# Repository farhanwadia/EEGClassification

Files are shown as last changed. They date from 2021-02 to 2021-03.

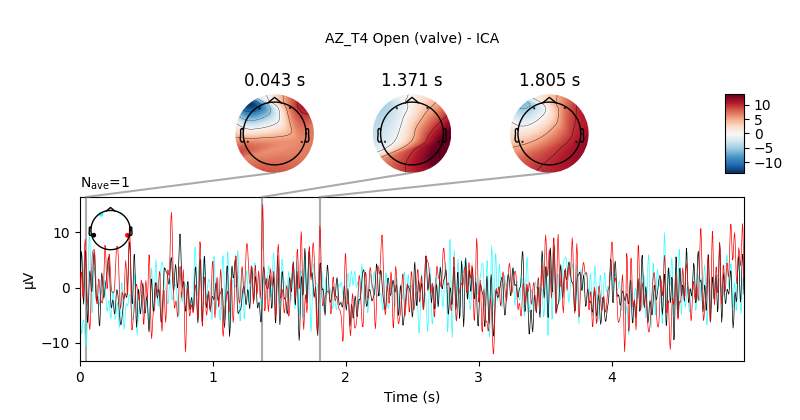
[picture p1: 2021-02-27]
Nov 2020 Filtered Data/5s/Images/ICA Images/AZ_T4 Open (valve) ICA.png

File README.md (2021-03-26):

# Brain Computer Interfaces for Industrial Fluid Flow Control

## Group Members
**Amaani Zuberi**

**Farhan Wadia**

**Jun Sung Park**

**Mrinal Jha** 

**Stephanie DiNunzio**

## Description
This repository consists of all data and software developed for our capstone project.

Programs for collecting EEG data based on covert speech, motor imagery, SSVEP, and eye movements can be found in the `Data Collection Scripts` folder. Follow the instructions in the `Using the Muse Headset for Collecting Raw EEG Signals.pdf` file within that folder to run any of the programs. Note that the MuseLab SDK is not included in this folder and will need to be installed separately.

Raw data files we collected for covert speech model training can be found in the `Nov 2020 Raw Data` and `Feb 2021 Raw Data` folders.

Filtering, time series data outputs, FFT outputs, wavelet transforms, and corresponding graphs were all developed using the `visualization.py` script. Outputs can be found organized in the `Nov 2020 Filtered Data` and `Feb 2021 Filtered Data` folders. 

Model training can be found in the `EEG_Classification_Model_Training.ipynb` notebook. Downloaded model weight files can be found in the `Trained Model Weights` folder. Testing for these models is conducted in the `EEG_Classification_Model_Testing.ipynb` notebook. A breakdown of the results for our final chosen model can be found in the `Final Model Test Results Summary.xlsx` spreadsheet.

Relevant files for implementing the chosen model live in conjunction with a solenoid valve can be found in the `Final Prototype Implementation` folder. Refer to the `Using the Muse Headset for Collecting Raw EEG Signals.pdf` file for further instructions on how to set up the Muse for live EEG streaming, and also refer to `Implementation_README.md`

The `Prototype and Final Design CAD Assemblies` folder contains SOLIDWORKS parts and assemblies showing the mechanical design of our system. The `Electrical Design` folder contains our final and previous versions of the electrical design, and includes the schematic, `.brd` files of the CAD in EAGLE, and `.step` file that can be imported into SOLIDWORKS.

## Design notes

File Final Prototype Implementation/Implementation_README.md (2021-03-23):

# Final Prototype Implementation Files

 - All these files MUST be kept in the same folder
 - If your GPU is not compatible with CUDA, you will need to set use_cuda = False
 - Make sure you change the save file path and subject initials before running
 
For the `output_ bluetooth.py` script, you will need to first pair the Bluetooth module with your computer. The code for Bluetooth pairing is 1234, but if that doesn't work, try 0000. The COM port may be different on your device, so check and change that if needed (may need different syntax for COM port on Mac).

In order to operate the valve, the python script `output_bluetooth.py` must be left continuously running on your computer and paired with the Bluetooth module on the circuit. The computer sends the input to the Bluetooth, not the mobile app. The mobile app will update an online database which the Python code is monitoring for updates to start recording. You will first need to set up the stream with Mind Monitor as you have for all other scripts (see the `Data Collection Scripts` folder for further details).

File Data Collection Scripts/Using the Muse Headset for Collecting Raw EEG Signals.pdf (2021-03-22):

# Using Muse 2016

# For recording/streaming EEG Raw Data

# Required Devices / Software

## - Phone or Tablet

- Need to install Mind Monitor App

## - Computer

- Need to install MuseLab (files in google drive folder) (https://drive.google.com/drive/folders/1IQV2IxdR8nq0KHTpxT8a-IwdV5VQzaGj?usp=sharing)
- Need to have python installed

## NOTE: My instructions are for using Windows 10, unsure if there are differences using MacOS

## Also note: The Mind Monitor App and MuseLab both have recording functions to export to CSV, however control of duration and ability to do file naming based on classification is limited and more time consuming than using python script

# 1. Connect Muse to phone/tablet

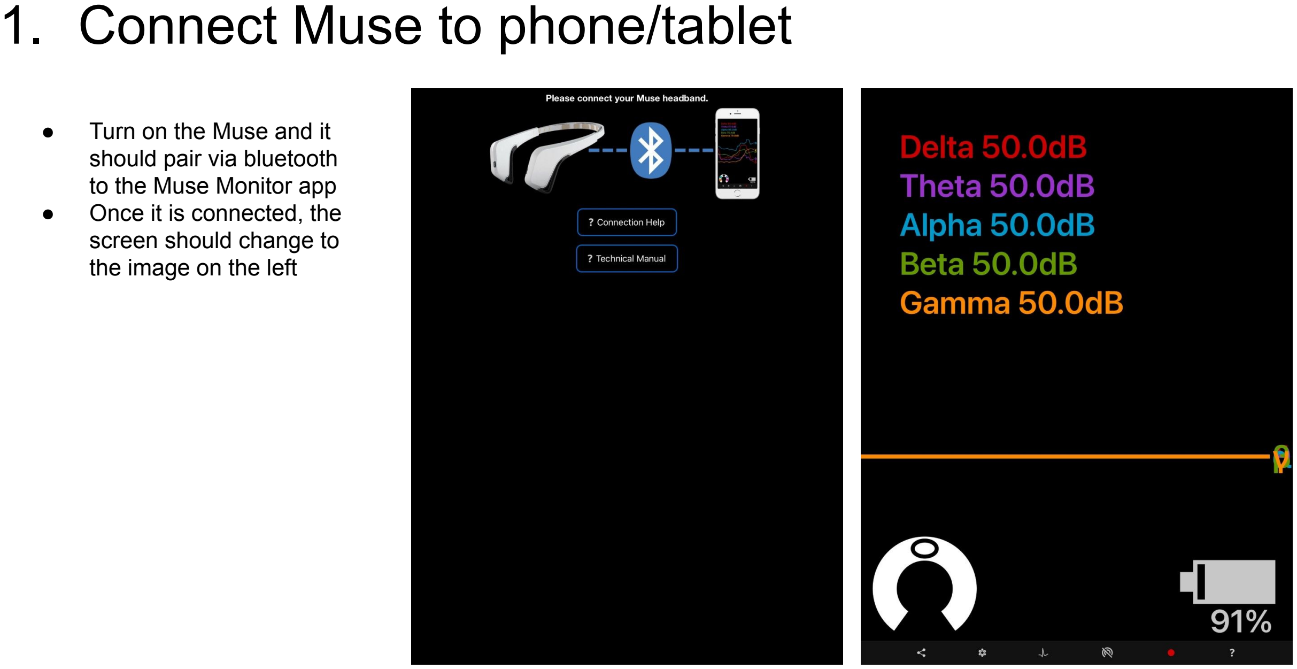
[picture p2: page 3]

- Turn on the Muse and it
should pair via bluetooth
to the Muse Monitor app
- Once it is connected, the screen should change to
the image on the left

# 2. Using the Muse Monitor App

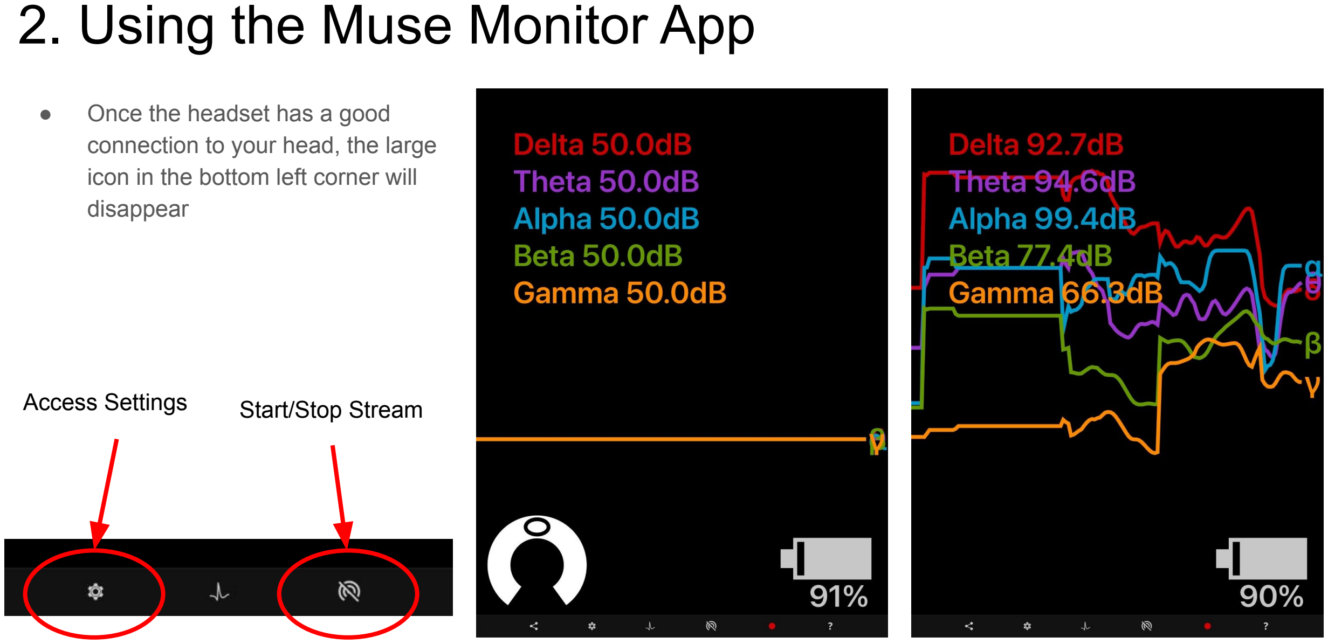
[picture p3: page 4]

- Once the headset has a good connection to your head, the large icon in the bottom left corner will disappear

Access Settings Start/Stop Stream

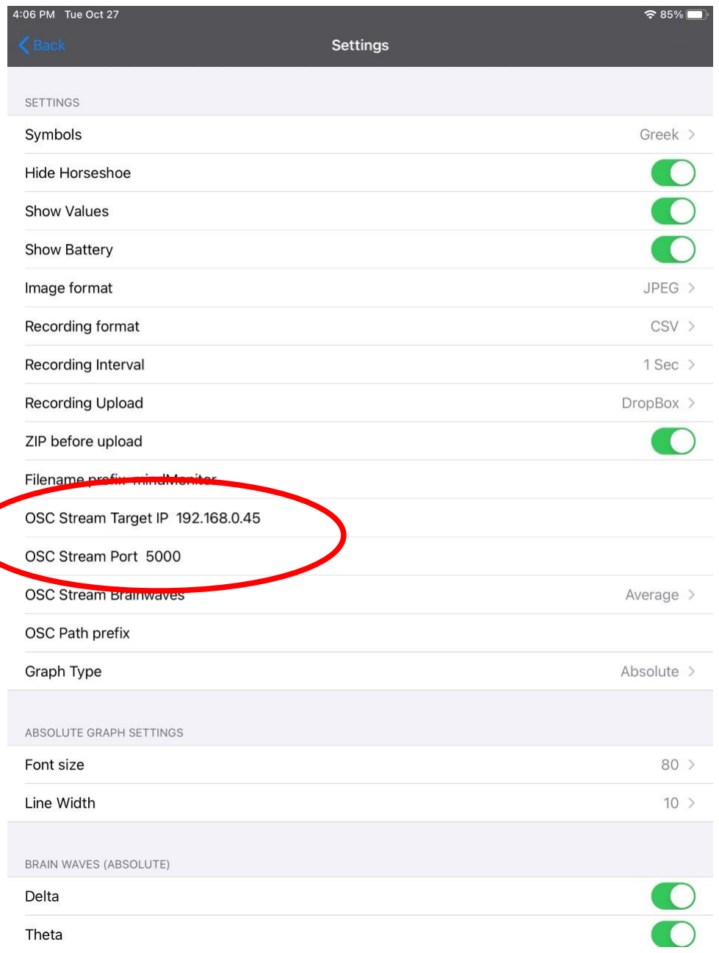
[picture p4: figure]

# 2. Using the Muse Monitor App Cont

- In order to stream to your computer, both devices must be connected to the same network
- If your computer has an ethernet connection, consider using your computer to create a hotspot for your phone or tablet, or switch to wifi
- OSC Stream Target IP must match the IP address of your computer
- Type ipconfig into the command prompt to check your IP address
- OSC Stream port must match the port used in MuseLab (we will use 5000)

# 3. Using MuseLab

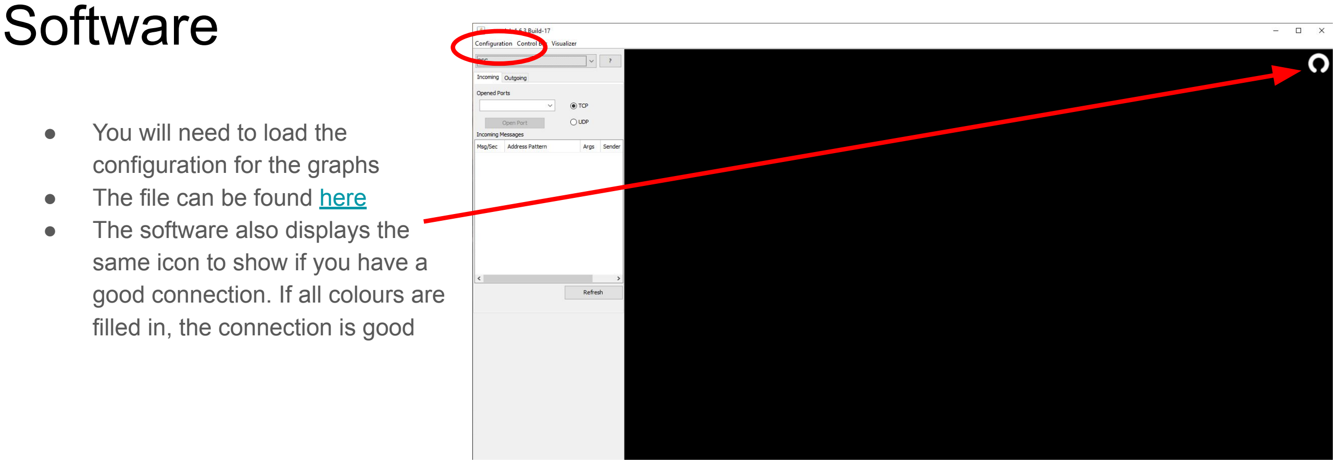
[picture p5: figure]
Software; ● You will need to load the configuration for the graphs; The file can be found; here; ● The software also displays the same icon to show if you have a good connection. If all colours are filled in, the connection is good

# 3. Using MuseLab

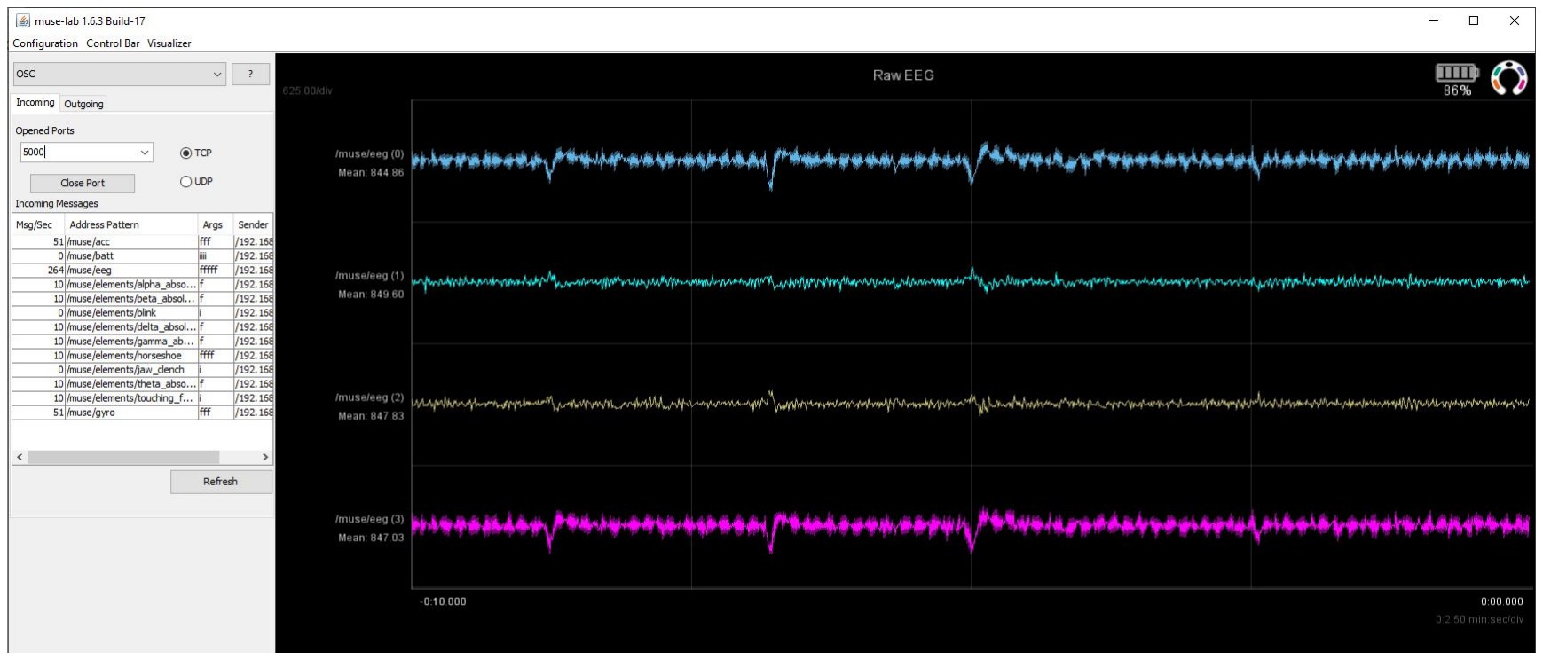
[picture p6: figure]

# Software Cont

- Open TCP Port 5000
- If the data is streaming correctly, it should look something like this
- If it is not streaming, try checking your settings on the Mind Monitor app and stopping and starting the stream on the app again
- Note: Keep in mind that if your computer is not using a static IP, it can change between uses. So you may want to double check this first, if it is not streaming.

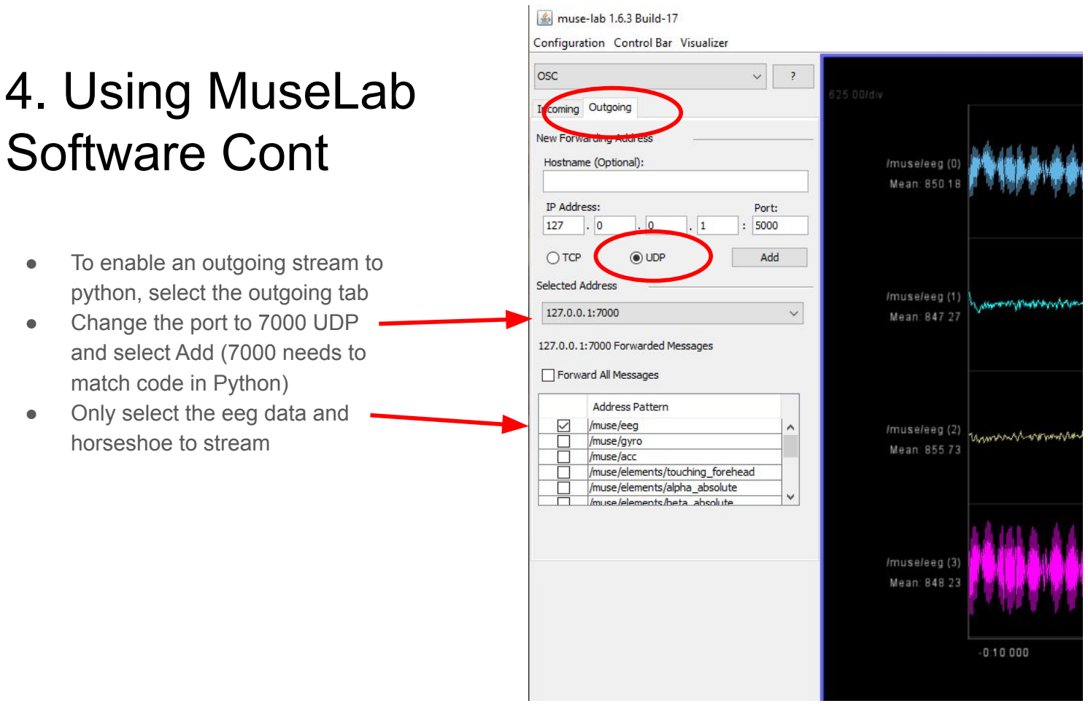
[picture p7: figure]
4. Using MuseLab Software Cont; ● To enable an outgoing stream to python, select the outgoing tab ● Change the port to 7000 UDP and select Add (7000 needs to match code in Python) ● Only select the eeg data and horseshoe to stream

# 5. Using Muse with Python

## - Run code for associated method

## a) SSVEP

# 5. a) - SSVEP Data Collection - Step 1

Open the SSVEP Data Collection.py file and scroll to the main() function at the bottom.

Change the subject to your initials and folderPath to a valid folder path where you will save all your files

Complete trials 1 to 48. Modify startTrialNum and endTrialNum if you do not want to do all these trials at once and only want to do selected trials in between, or leave it as shown to do all the trials at once

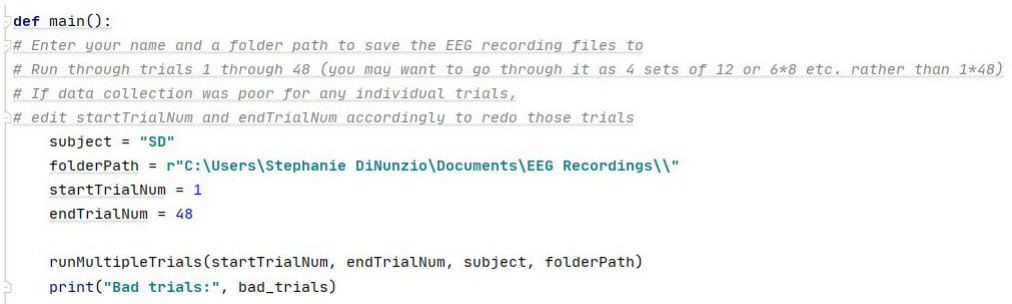
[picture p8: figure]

Run the program

# 5. a) - SSVEP Data Collection - Step 2

At the start of each trial, a rest screen will show for 10 -15s . EEG data will be recorded as you rest. The rest screen also informs you which side of the screen you will be looking at in the next step.

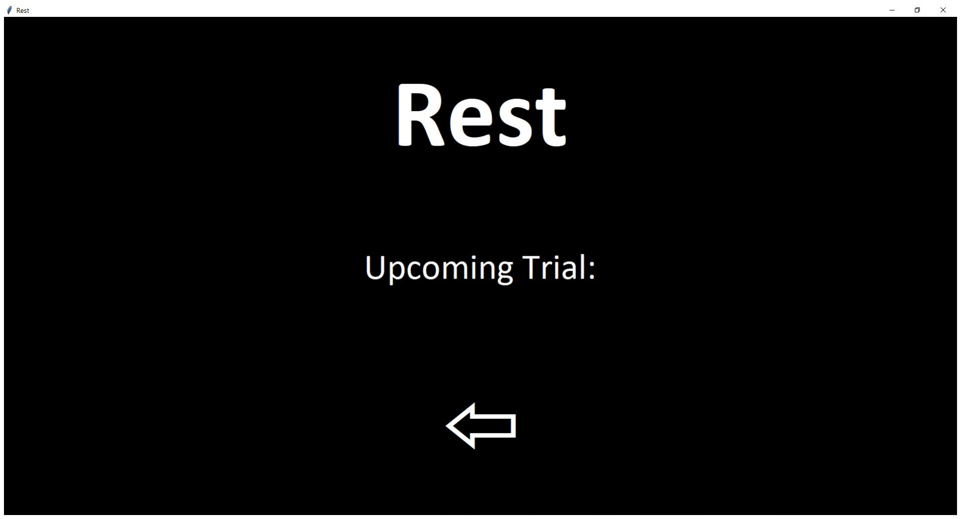
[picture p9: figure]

# 5. a) - SSVEP Data Collection - Step 3

Stare at the flashing checkerboard and red dot on the side of the screen indicated to you. EEG data will be recorded as you do this

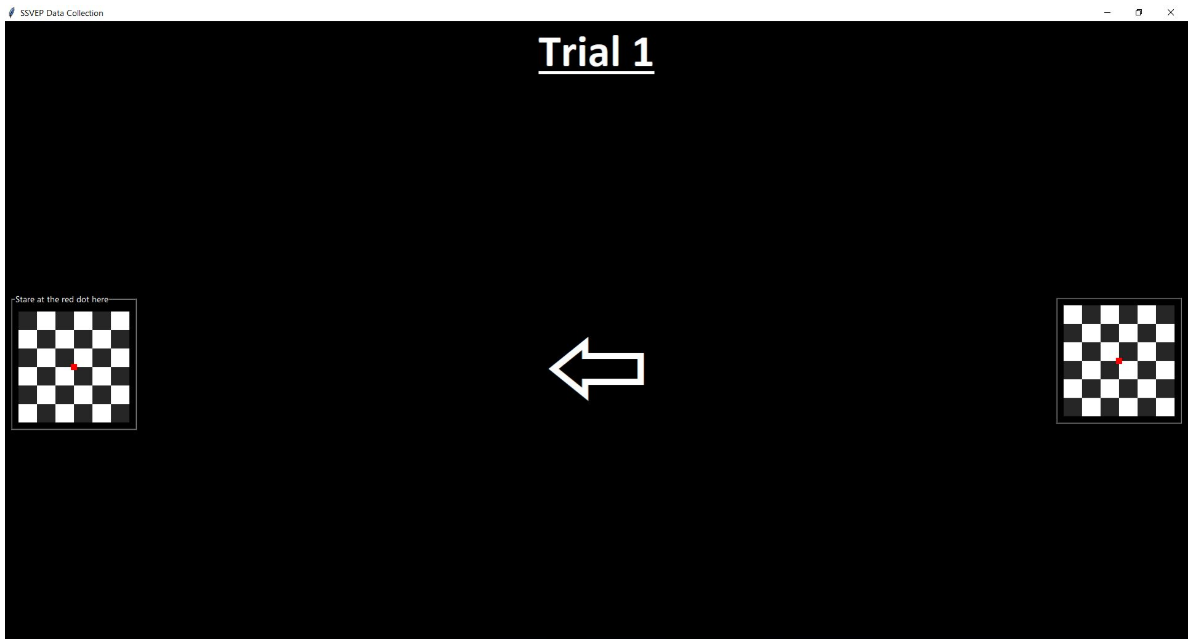
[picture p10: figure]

# 5. a) - SSVEP Data Collection - Step 4

After steps 2 and 3 have been completed for all the trials chosen in step 1, check the Python console to see if any recordings had a poor connection.

If there is a message similar to the one shown below, go back to step 1 and repeat those particular trials

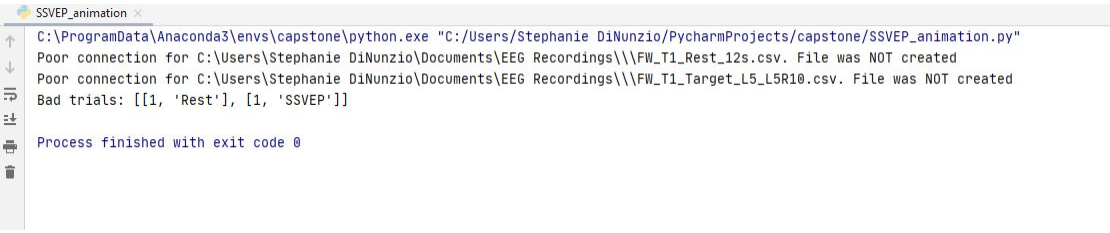
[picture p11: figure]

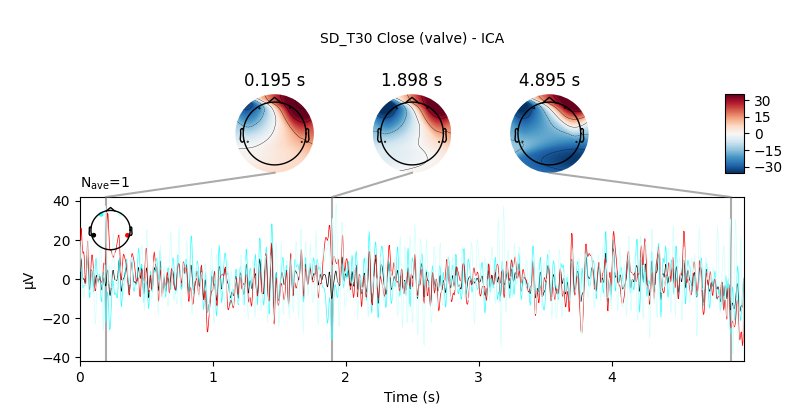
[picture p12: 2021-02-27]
Nov 2020 Filtered Data/5s/Images/ICA Images/SD_T30 Close (valve) ICA.png

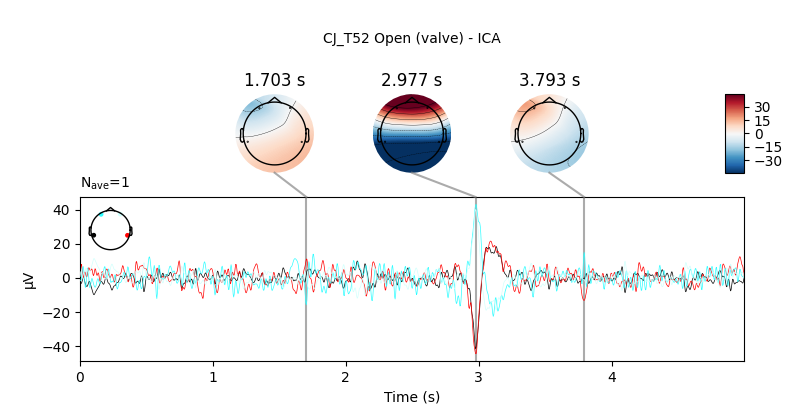
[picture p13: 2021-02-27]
Nov 2020 Filtered Data/5s/Images/ICA Images/CJ_T52 Open (valve) ICA.png

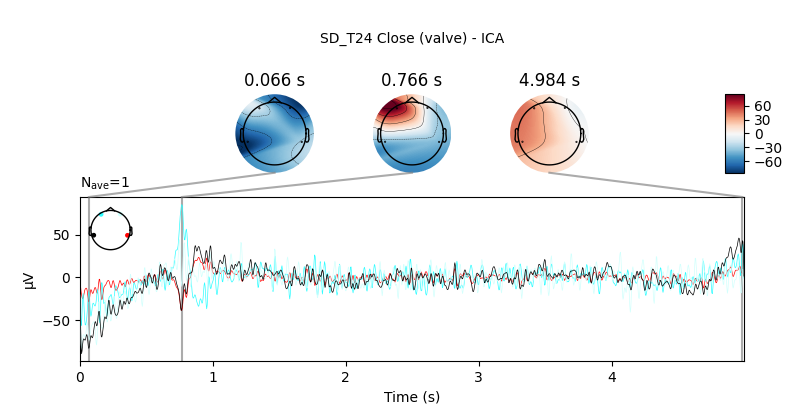
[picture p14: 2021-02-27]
Nov 2020 Filtered Data/5s/Images/ICA Images/SD_T24 Close (valve) ICA.png

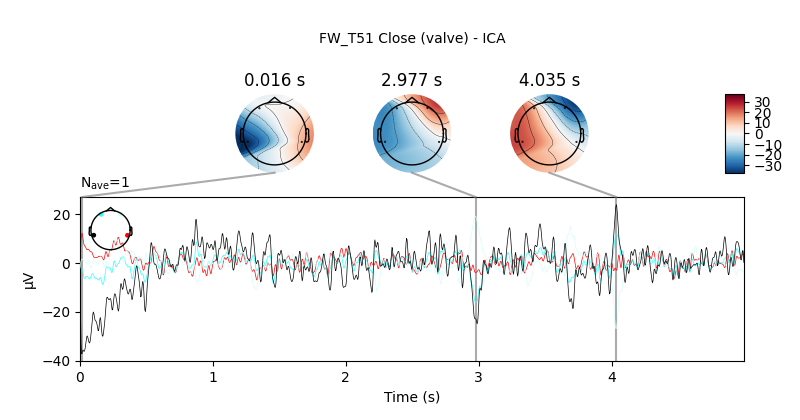
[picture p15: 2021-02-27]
Nov 2020 Filtered Data/5s/Images/ICA Images/FW_T51 Close (valve) ICA.png

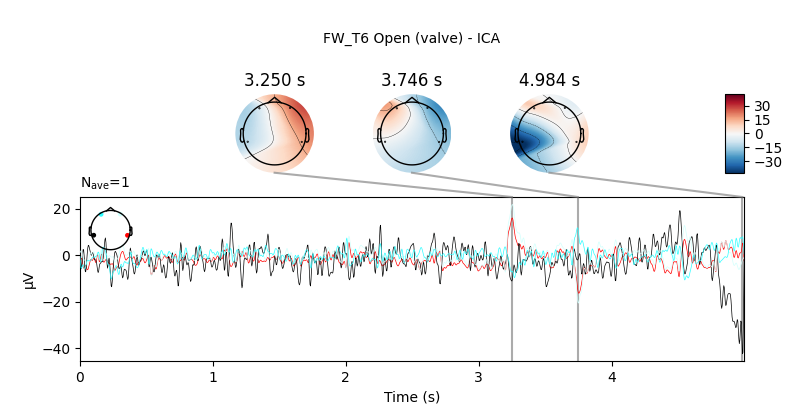
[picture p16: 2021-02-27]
Nov 2020 Filtered Data/5s/Images/ICA Images/FW_T6 Open (valve) ICA.png

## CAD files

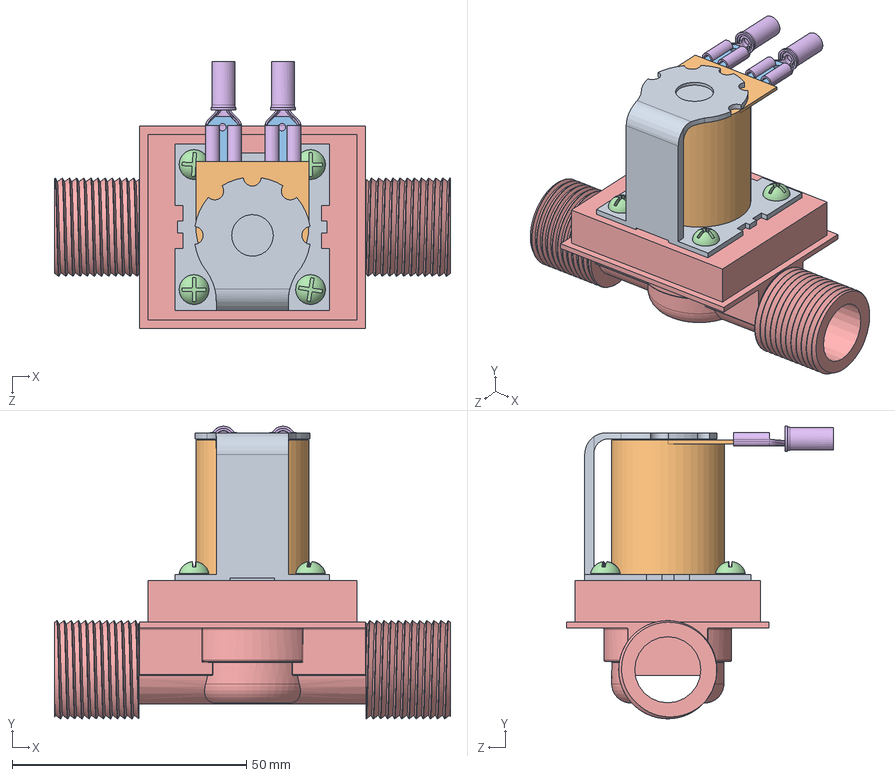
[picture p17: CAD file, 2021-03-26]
Prototype and Final Design CAD Assemblies/Other Assemblies/assemb2.SLDASM
84.6 x 62.5 x 56.9 mm
CAGE
LEAD x 2
screw x 4
Solenoid

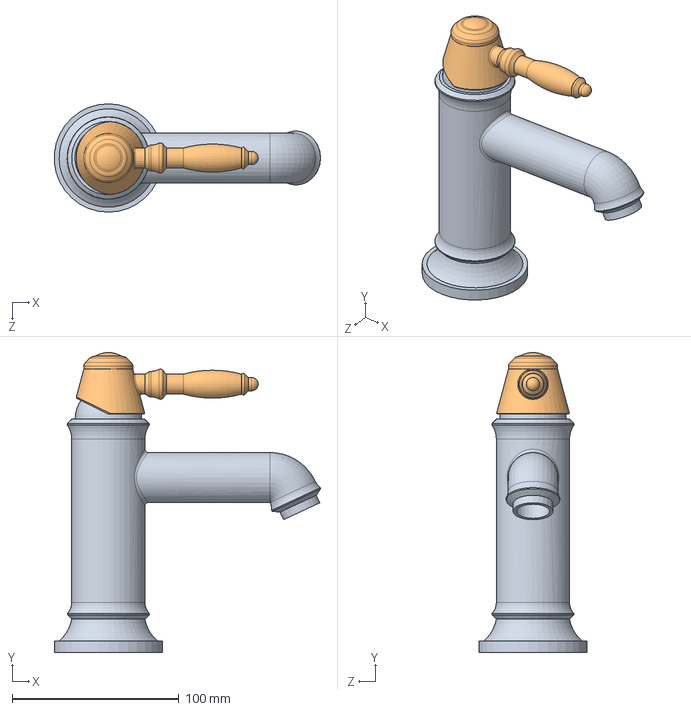
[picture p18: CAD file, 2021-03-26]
Prototype and Final Design CAD Assemblies/Parts/Bathroom faucet/Bathroom_faucet.SLDASM
159.7 x 180.0 x 65.0 mm
base
Handle

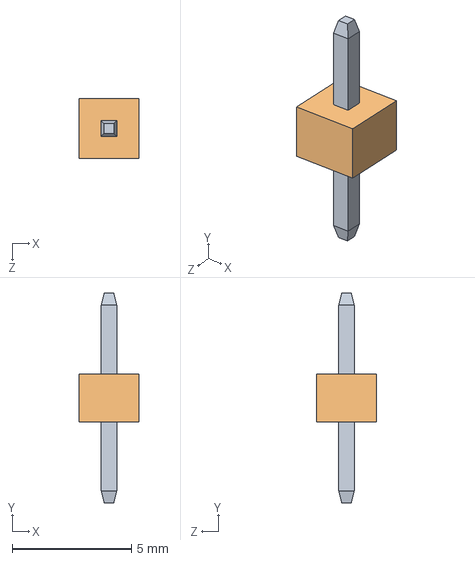
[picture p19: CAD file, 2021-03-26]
Prototype and Final Design CAD Assemblies/Parts/Jumper.SLDASM
2.50 x 8.80 x 2.50 mm
Pin
Socket

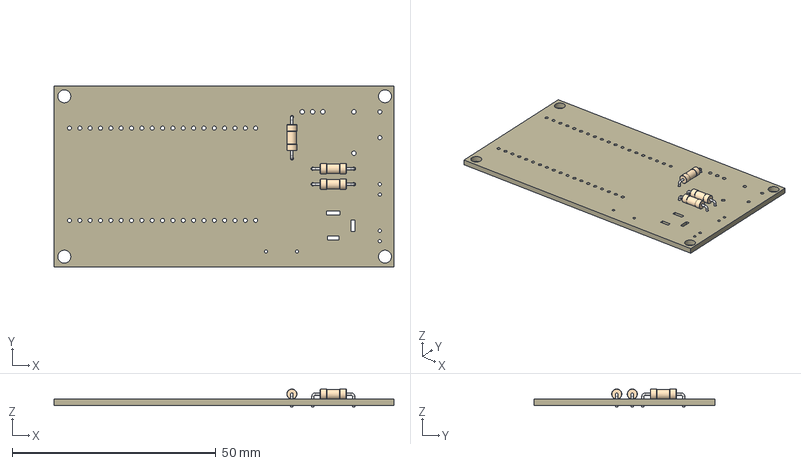
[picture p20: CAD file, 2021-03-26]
Electrical Design/capstone electrical circuit v11.step
83.5 x 44.4 x 4.42 mm
Board
DO41-10
0207/10 x 3
2,54/1,0 x 2
ESP32-DEVKITC
DCJ0202

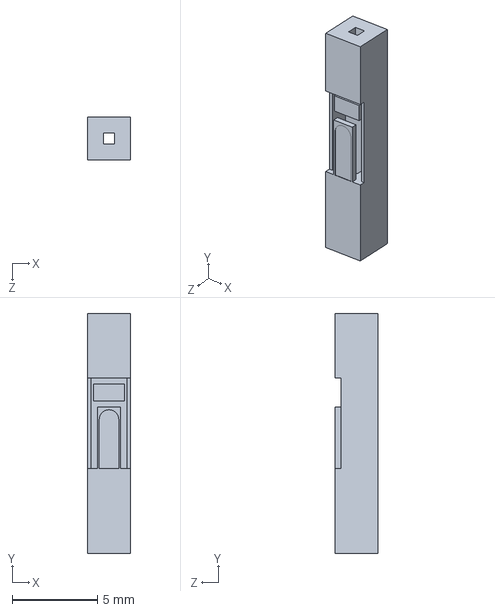
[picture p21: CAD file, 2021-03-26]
Prototype and Final Design CAD Assemblies/Parts/Socket.SLDPRT
2.50 x 14.1 x 2.50 mm

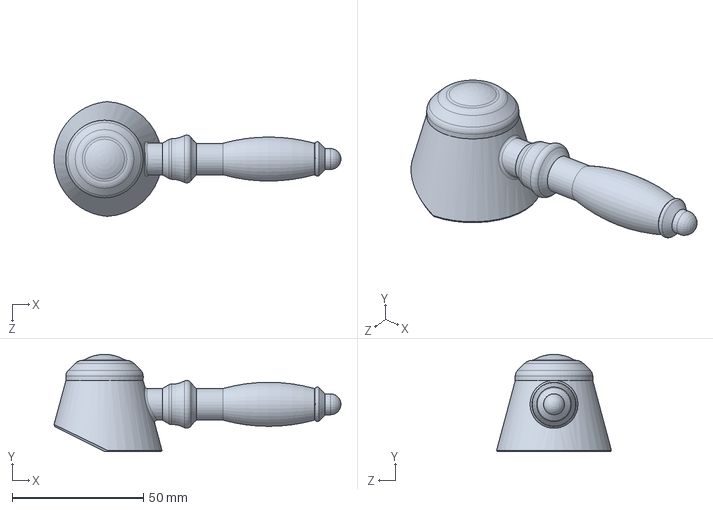
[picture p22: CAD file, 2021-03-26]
Prototype and Final Design CAD Assemblies/Parts/Bathroom faucet/Handle.SLDPRT
109.2 x 37.0 x 43.7 mm

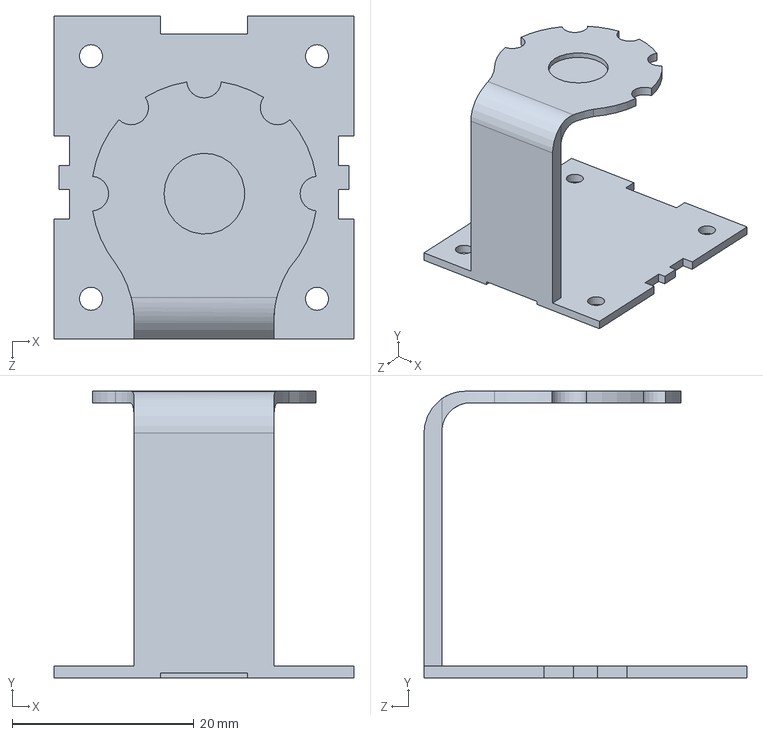
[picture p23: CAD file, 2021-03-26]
Prototype and Final Design CAD Assemblies/Parts/CAGE.SLDPRT
33.0 x 31.5 x 35.6 mm

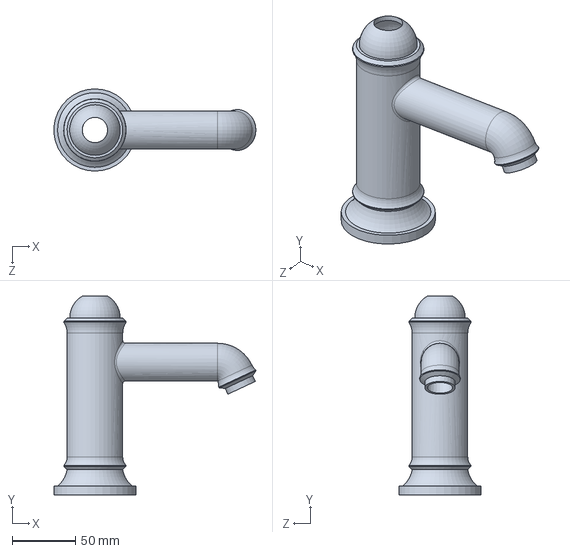
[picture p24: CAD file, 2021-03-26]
Prototype and Final Design CAD Assemblies/Parts/Bathroom faucet/base.SLDPRT
159.7 x 157.3 x 65.0 mm

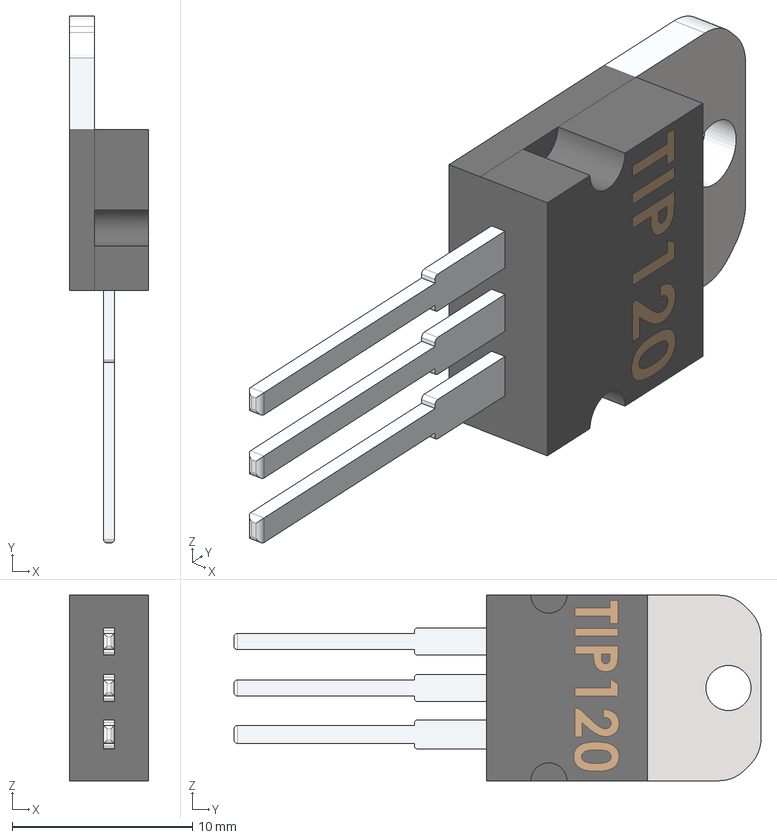
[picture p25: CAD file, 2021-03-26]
Prototype and Final Design CAD Assemblies/Parts/TIP120.step
4.39 x 29.2 x 10.3 mm

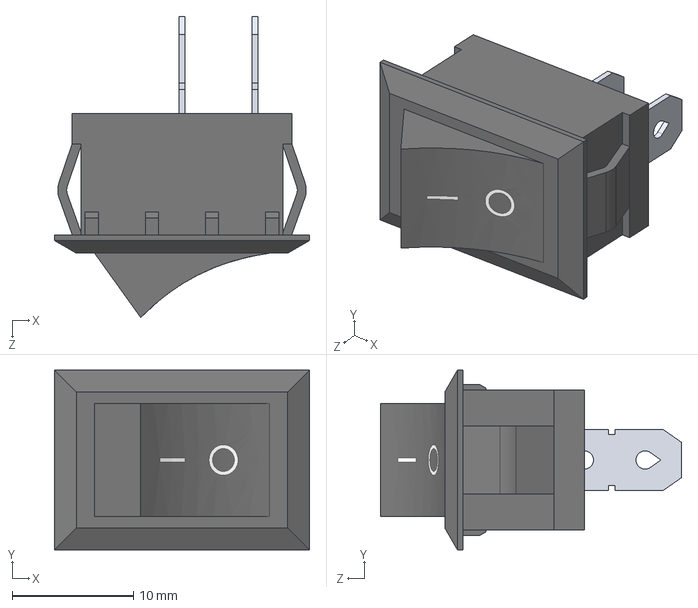
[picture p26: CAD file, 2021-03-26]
Prototype and Final Design CAD Assemblies/Parts/RockerSwitch.STEP
21.0 x 14.8 x 24.8 mm

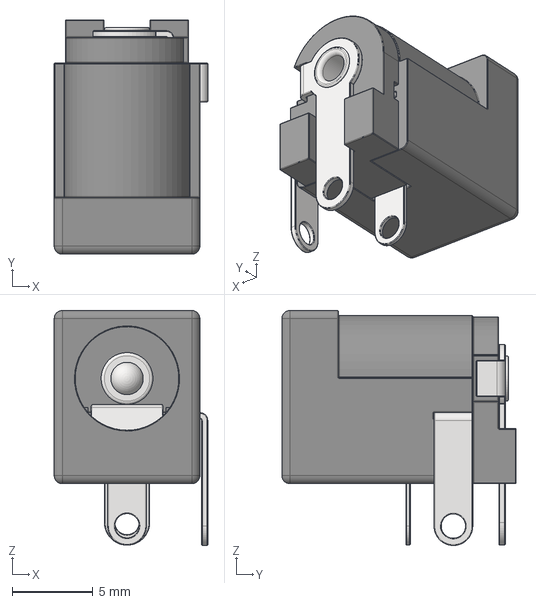
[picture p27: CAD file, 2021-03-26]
Prototype and Final Design CAD Assemblies/Parts/Power Barrel Connector Jack 694106301002.stp
9.49 x 14.5 x 14.5 mm

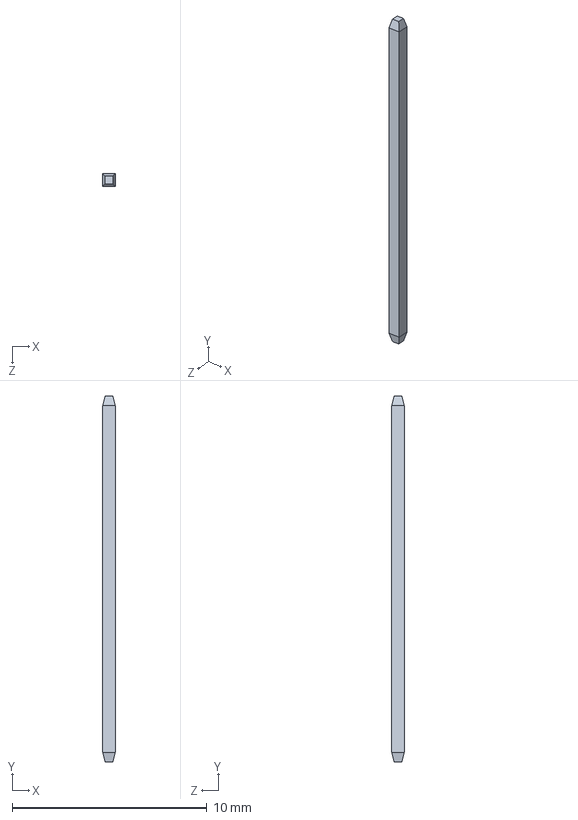
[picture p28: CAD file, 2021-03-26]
Prototype and Final Design CAD Assemblies/Parts/Pin.SLDPRT
0.65 x 18.8 x 0.65 mm

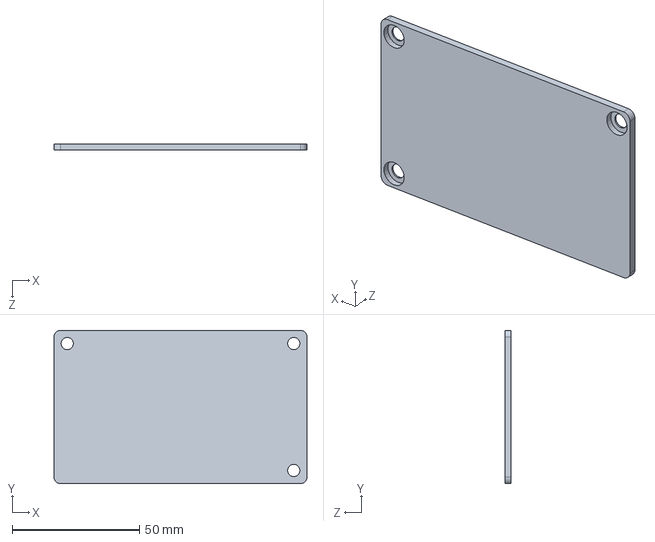
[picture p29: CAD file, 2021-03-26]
Prototype and Final Design CAD Assemblies/Parts/caselid.SLDPRT
99.3 x 60.2 x 2.54 mm

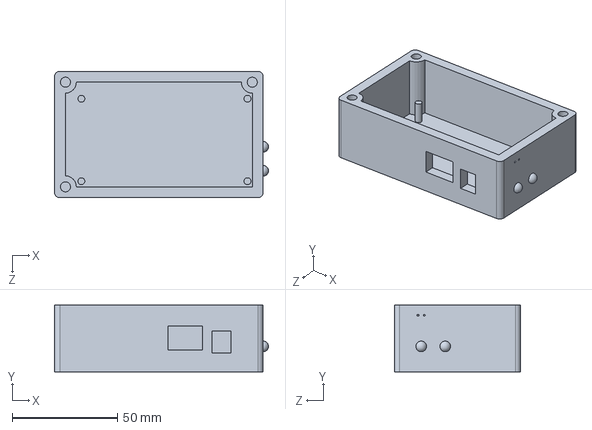
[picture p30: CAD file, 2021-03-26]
Prototype and Final Design CAD Assemblies/Parts/case4.SLDPRT
101.8 x 31.8 x 60.2 mm

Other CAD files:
Prototype and Final Design CAD Assemblies/Parts/Power Diode 1N4001.step
Prototype and Final Design CAD Assemblies/Parts/Solenoid.SLDPRT
Prototype and Final Design CAD Assemblies/Parts/cylinder.SLDPRT
Prototype and Final Design CAD Assemblies/Parts/LEAD.SLDPRT
Electrical Design/Previous Versions/v1/capstone electrical circuit v1.step
Electrical Design/Previous Versions/v2/capstone electrical circuit v4.step
Prototype and Final Design CAD Assemblies/Parts/55675-1.SLDPRT
Prototype and Final Design CAD Assemblies/Parts/LED 3mm, Green, Thru-hole, Right Angle PCB 2.stp
Prototype and Final Design CAD Assemblies/Parts/LED 3mm, Red, Thru-hole, Right Angle PCB 2.stp
Prototype and Final Design CAD Assemblies/Parts/RockerSwitch.x_t
Prototype and Final Design CAD Assemblies/Parts/screw.SLDPRT

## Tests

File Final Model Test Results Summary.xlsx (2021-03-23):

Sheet: Testing Notebook Output
Set | Notebook Output
Training | Prediction: 1 | Label: 1 | Status: Prediction Correct | File: /content/EEGClassification//Feb 2021 Filtered Data//5s//OPEN//SD_T5 Open (valve)_(1) - Filtered
Training | Prediction: 0 | Label: 1 | Status: Prediction Incorrect | File: /content/EEGClassification//Nov 2020 Filtered Data//5s//OPEN//AZ_T39 Open (valve) - Filtered
Training | Prediction: 1 | Label: 1 | Status: Prediction Correct | File: /content/EEGClassification//Feb 2021 Filtered Data//5s//OPEN//CJ_T35 Open (valve)_(2) - Filtered
Training | Prediction: 1 | Label: 1 | Status: Prediction Correct | File: /content/EEGClassification//Nov 2020 Filtered Data//5s//OPEN//FW_T75 Open (valve) - Filtered
Training | Prediction: 0 | Label: 1 | Status: Prediction Incorrect | File: /content/EEGClassification//Feb 2021 Filtered Data//5s//OPEN//CJ2_T1 Open (valve) - Filtered
Training | Prediction: 1 | Label: 1 | Status: Prediction Correct | File: /content/EEGClassification//Feb 2021 Filtered Data//5s//OPEN//FW_T27 Open (valve) - Filtered
Training | Prediction: 1 | Label: 1 | Status: Prediction Correct | File: /content/EEGClassification//Feb 2021 Filtered Data//5s//OPEN//CJ2_T3 Open (valve) - Filtered
Training | Prediction: 1 | Label: 1 | Status: Prediction Correct | File: /content/EEGClassification//Nov 2020 Filtered Data//5s//OPEN//SD_T15 Open (valve) - Filtered
Training | Prediction: 1 | Label: 1 | Status: Prediction Correct | File: /content/EEGClassification//Feb 2021 Filtered Data//5s//OPEN//JP2_T13 Open (valve)_(1) - Filtered
Training | Prediction: 1 | Label: 1 | Status: Prediction Correct | File: /content/EEGClassification//Nov 2020 Filtered Data//5s//OPEN//SD_T14 Open (valve) - Filtered
Training | Prediction: 1 | Label: 1 | Status: Prediction Correct | File: /content/EEGClassification//Nov 2020 Filtered Data//5s//OPEN//AZ_T75 Open (valve) - Filtered
Training | Prediction: 1 | Label: 1 | Status: Prediction Correct | File: /content/EEGClassification//Feb 2021 Filtered Data//5s//OPEN//AZ_T13 Open (valve) - Filtered
Training | Prediction: 1 | Label: 1 | Status: Prediction Correct | File: /content/EEGClassification//Feb 2021 Filtered Data//5s//OPEN//CJ_T21 Open (valve) - Filtered
Training | Prediction: 1 | Label: 1 | Status: Prediction Correct | File: /content/EEGClassification//Nov 2020 Filtered Data//5s//OPEN//AZ_T55 Open (valve) - Filtered
Training | Prediction: 1 | Label: 1 | Status: Prediction Correct | File: /content/EEGClassification//Feb 2021 Filtered Data//5s//OPEN//CJ_T25 Open (valve)_(2) - Filtered
Training | Prediction: 1 | Label: 1 | Status: Prediction Correct | File: /content/EEGClassification//Nov 2020 Filtered Data//5s//OPEN//AZ_T57 Open (valve) - Filtered
Training | Prediction: 1 | Label: 1 | Status: Prediction Correct | File: /content/EEGClassification//Feb 2021 Filtered Data//5s//OPEN//CJ_T11 Open (valve) - Filtered
Training | Prediction: 1 | Label: 1 | Status: Prediction Correct | File: /content/EEGClassification//Nov 2020 Filtered Data//5s//OPEN//FW_T32 Open (valve) - Filtered
Training | Prediction: 1 | Label: 1 | Status: Prediction Correct | File: /content/EEGClassification//Feb 2021 Filtered Data//5s//OPEN//FW2_T37 Open (valve) - Filtered
Training | Prediction: 1 | Label: 1 | Status: Prediction Correct | File: /content/EEGClassification//Feb 2021 Filtered Data//5s//OPEN//CJ2_T9 Open (valve) - Filtered
Training | Prediction: 1 | Label: 1 | Status: Prediction Correct | File: /content/EEGClassification//Feb 2021 Filtered Data//5s//OPEN//CJ_T39 Open (valve)_(1) - Filtered
Training | Prediction: 1 | Label: 1 | Status: Prediction Correct | File: /content/EEGClassification//Feb 2021 Filtered Data//5s//OPEN//FW_T35 Open (valve) - Filtered
Training | Prediction: 1 | Label: 1 | Status: Prediction Correct | File: /content/EEGClassification//Nov 2020 Filtered Data//5s//OPEN//FW_T34 Open (valve) - Filtered
Training | Prediction: 0 | Label: 1 | Status: Prediction Incorrect | File: /content/EEGClassification//Feb 2021 Filtered Data//5s//OPEN//SD_T17 Open (valve) - Filtered
Training | Prediction: 1 | Label: 1 | Status: Prediction Correct | File: /content/EEGClassification//Nov 2020 Filtered Data//5s//OPEN//AZ_T65 Open (valve) - Filtered
Training | Prediction: 0 | Label: 1 | Status: Prediction Incorrect | File: /content/EEGClassification//Nov 2020 Filtered Data//5s//OPEN//SD_T1 Open (valve)_(1) - Filtered
Training | Prediction: 1 | Label: 1 | Status: Prediction Correct | File: /content/EEGClassification//Feb 2021 Filtered Data//5s//OPEN//JP_T5 Open (valve) - Filtered
Training | Prediction: 1 | Label: 1 | Status: Prediction Correct | File: /content/EEGClassification//Nov 2020 Filtered Data//5s//OPEN//SD_T12 Open (valve)_(1) - Filtered
Training | Prediction: 1 | Label: 1 | Status: Prediction Correct | File: /content/EEGClassification//Nov 2020 Filtered Data//5s//OPEN//CJ_T45 Open (valve) - Filtered
Training | Prediction: 1 | Label: 1 | Status: Prediction Correct | File: /content/EEGClassification//Feb 2021 Filtered Data//5s//OPEN//CJ_T35 Open (valve)_(1) - Filtered
Training | Prediction: 1 | Label: 1 | Status: Prediction Correct | File: /content/EEGClassification//Nov 2020 Filtered Data//5s//OPEN//FW_T19 Open (valve) - Filtered
Training | Prediction: 1 | Label: 1 | Status: Prediction Correct | File: /content/EEGClassification//Nov 2020 Filtered Data//5s//OPEN//SD_T13 Open (valve) - Filtered
Training | Prediction: 1 | Label: 1 | Status: Prediction Correct | File: /content/EEGClassification//Feb 2021 Filtered Data//5s//OPEN//SD_T17 Open (valve)_(1) - Filtered
Training | Prediction: 1 | Label: 1 | Status: Prediction Correct | File: /content/EEGClassification//Nov 2020 Filtered Data//5s//OPEN//CJ_T58 Open (valve) - Filtered
Training | Prediction: 1 | Label: 1 | Status: Prediction Correct | File: /content/EEGClassification//Nov 2020 Filtered Data//5s//OPEN//FW_T56 Open (valve) - Filtered
Training | Prediction: 1 | Label: 1 | Status: Prediction Correct | File: /content/EEGClassification//Feb 2021 Filtered Data//5s//OPEN//FW_T29 Open (valve) - Filtered
Training | Prediction: 1 | Label: 1 | Status: Prediction Correct | File: /content/EEGClassification//Feb 2021 Filtered Data//5s//OPEN//CJ_T9 Open (valve) - Filtered
Training | Prediction: 1 | Label: 1 | Status: Prediction Correct | File: /content/EEGClassification//Nov 2020 Filtered Data//5s//OPEN//AZ_T62 Open (valve) - Filtered
Training | Prediction: 1 | Label: 1 | Status: Prediction Correct | File: /content/EEGClassification//Feb 2021 Filtered Data//5s//OPEN//CJ_T13 Open (valve)_(1) - Filtered
Training | Prediction: 1 | Label: 1 | Status: Prediction Correct | File: /content/EEGClassification//Feb 2021 Filtered Data//5s//OPEN//CJ_T7 Open (valve)_(2) - Filtered
Training | Prediction: 1 | Label: 1 | Status: Prediction Correct | File: /content/EEGClassification//Feb 2021 Filtered Data//5s//OPEN//FW_T7 Open (valve) - Filtered
Training | Prediction: 1 | Label: 1 | Status: Prediction Correct | File: /content/EEGClassification//Nov 2020 Filtered Data//5s//OPEN//CJ_T29 Open (valve) - Filtered
Training | Prediction: 1 | Label: 1 | Status: Prediction Correct | File: /content/EEGClassification//Feb 2021 Filtered Data//5s//OPEN//SD_T23 Open (valve) - Filtered
Training | Prediction: 1 | Label: 1 | Status: Prediction Correct | File: /content/EEGClassification//Feb 2021 Filtered Data//5s//OPEN//CJ_T23 Open (valve)_(2) - Filtered
Training | Prediction: 1 | Label: 1 | Status: Prediction Correct | File: /content/EEGClassification//Feb 2021 Filtered Data//5s//OPEN//JP_T31 Open (valve) - Filtered
Training | Prediction: 1 | Label: 1 | Status: Prediction Correct | File: /content/EEGClassification//Feb 2021 Filtered Data//5s//OPEN//CJ_T37 Open (valve) - Filtered
Training | Prediction: 1 | Label: 1 | Status: Prediction Correct | File: /content/EEGClassification//Feb 2021 Filtered Data//5s//OPEN//JP_T1 Open (valve) - Filtered
Training | Prediction: 1 | Label: 1 | Status: Prediction Correct | File: /content/EEGClassification//Feb 2021 Filtered Data//5s//OPEN//FW2_T1 Open (valve) - Filtered
Training | Prediction: 1 | Label: 1 | Status: Prediction Correct | File: /content/EEGClassification//Nov 2020 Filtered Data//5s//OPEN//AZ_T24 Open (valve) - Filtered
Training | Prediction: 1 | Label: 1 | Status: Prediction Correct | File: /content/EEGClassification//Feb 2021 Filtered Data//5s//OPEN//JP2_T11 Open (valve)_(1) - Filtered
Training | Prediction: 1 | Label: 1 | Status: Prediction Correct | File: /content/EEGClassification//Nov 2020 Filtered Data//5s//OPEN//AZ_T44 Open (valve) - Filtered
Training | Prediction: 1 | Label: 1 | Status: Prediction Correct | File: /content/EEGClassification//Nov 2020 Filtered Data//5s//OPEN//CJ_T18 Open (valve) - Filtered
Training | Prediction: 1 | Label: 1 | Status: Prediction Correct | File: /content/EEGClassification//Feb 2021 Filtered Data//5s//OPEN//CJ_T39 Open (valve)_(2) - Filtered
Training | Prediction: 1 | Label: 1 | Status: Prediction Correct | File: /content/EEGClassification//Feb 2021 Filtered Data//5s//OPEN//JP_T35 Open (valve) - Filtered
Training | Prediction: 1 | Label: 1 | Status: Prediction Correct | File: /content/EEGClassification//Nov 2020 Filtered Data//5s//OPEN//SD_T26 Open (valve)_(1) - Filtered
Training | Prediction: 1 | Label: 1 | Status: Prediction Correct | File: /content/EEGClassification//Feb 2021 Filtered Data//5s//OPEN//CJ_T3 Open (valve)_(2) - Filtered
Training | Prediction: 1 | Label: 1 | Status: Prediction Correct | File: /content/EEGClassification//Nov 2020 Filtered Data//5s//OPEN//SD_T12 Open (valve)_(2) - Filtered
Training | Prediction: 1 | Label: 1 | Status: Prediction Correct | File: /content/EEGClassification//Nov 2020 Filtered Data//5s//OPEN//FW_T71 Open (valve) - Filtered
Training | Prediction: 1 | Label: 1 | Status: Prediction Correct | File: /content/EEGClassification//Nov 2020 Filtered Data//5s//OPEN//CJ_T52 Open (valve) - Filtered
Training | Prediction: 1 | Label: 1 | Status: Prediction Correct | File: /content/EEGClassification//Feb 2021 Filtered Data//5s//OPEN//FW2_T31 Open (valve) - Filtered
Training | Prediction: 1 | Label: 1 | Status: Prediction Correct | File: /content/EEGClassification//Feb 2021 Filtered Data//5s//OPEN//FW3_T17 Open (valve) - Filtered
Training | Prediction: 1 | Label: 1 | Status: Prediction Correct | File: /content/EEGClassification//Feb 2021 Filtered Data//5s//OPEN//JP_T9 Open (valve) - Filtered
Training | Prediction: 1 | Label: 1 | Status: Prediction Correct | File: /content/EEGClassification//Nov 2020 Filtered Data//5s//OPEN//AZ_T8 Open (valve) - Filtered
Training | Prediction: 1 | Label: 1 | Status: Prediction Correct | File: /content/EEGClassification//Feb 2021 Filtered Data//5s//OPEN//FW3_T25 Open (valve) - Filtered
Training | Prediction: 1 | Label: 1 | Status: Prediction Correct | File: /content/EEGClassification//Feb 2021 Filtered Data//5s//OPEN//AZ_T25 Open (valve) - Filtered
Training | Prediction: 1 | Label: 1 | Status: Prediction Correct | File: /content/EEGClassification//Feb 2021 Filtered Data//5s//OPEN//FW3_T19 Open (valve) - Filtered
Training | Prediction: 1 | Label: 1 | Status: Prediction Correct | File: /content/EEGClassification//Feb 2021 Filtered Data//5s//OPEN//FW2_T13 Open (valve) - Filtered
Training | Prediction: 1 | Label: 1 | Status: Prediction Correct | File: /content/EEGClassification//Feb 2021 Filtered Data//5s//OPEN//SD_T11 Open (valve) - Filtered
Training | Prediction: 0 | Label: 1 | Status: Prediction Incorrect | File: /content/EEGClassification//Feb 2021 Filtered Data//5s//OPEN//JP_T21 Open (valve) - Filtered
Training | Prediction: 1 | Label: 1 | Status: Prediction Correct | File: /content/EEGClassification//Feb 2021 Filtered Data//5s//OPEN//CJ_T17 Open (valve)_(1) - Filtered
Training | Prediction: 0 | Label: 1 | Status: Prediction Incorrect | File: /content/EEGClassification//Feb 2021 Filtered Data//5s//OPEN//FW_T13 Open (valve) - Filtered
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

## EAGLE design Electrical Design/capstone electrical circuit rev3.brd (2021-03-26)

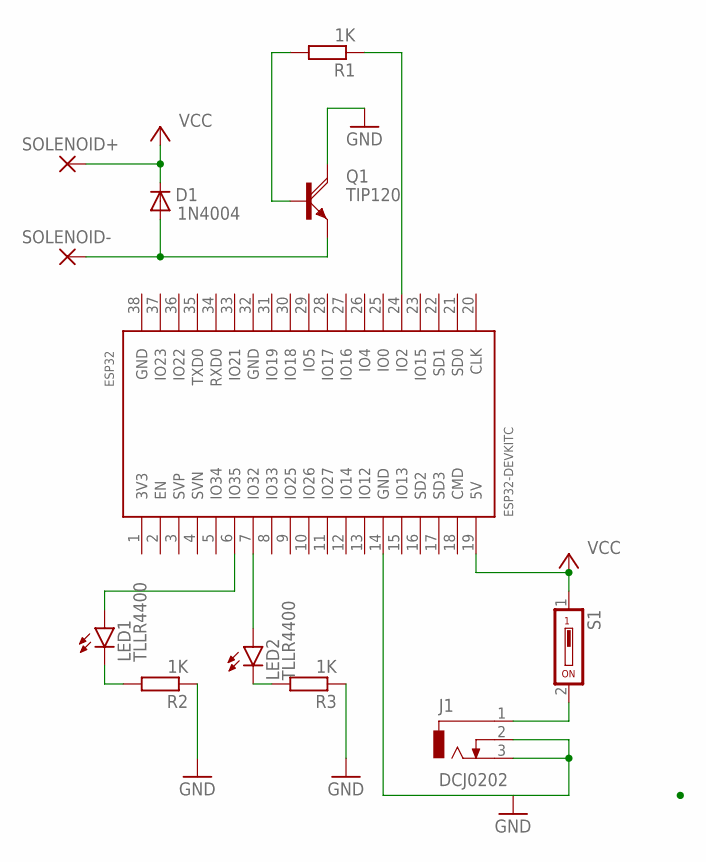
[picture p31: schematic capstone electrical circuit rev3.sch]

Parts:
D1: 1N4004; DO41-10
ESP32: ESP32DEVKITC; ESP32-DEVKITC
J1: DCJ0202
LED1, LED2: TLLR4400; LED3MM
Q1: TIP120; TO220AH
R1, R2, R3: 1K; 0207/10
S1: SD4-01
SOLENOID+: WIREPAD2,54/1,0; 2,54/1,0
SOLENOID-: WIREPAD2,54/1,0; 2,54/1,0

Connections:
GND: ESP32.14 (GND), J1.2, J1.3, Q1.C, R2.1, R3.1
unnamed: J1.1, S1.2
unnamed: LED1.K (C), R2.2
unnamed: D1.A, Q1.E, SOLENOID-.1
unnamed: Q1.B, R1.2
unnamed: ESP32.24 (IO2), R1.1
unnamed: LED2.K (C), R3.2
unnamed: ESP32.7 (IO32), LED2.A
unnamed: ESP32.6 (IO35), LED1.A
VCC: D1.C, ESP32.19 (5V), S1.1, SOLENOID+.1

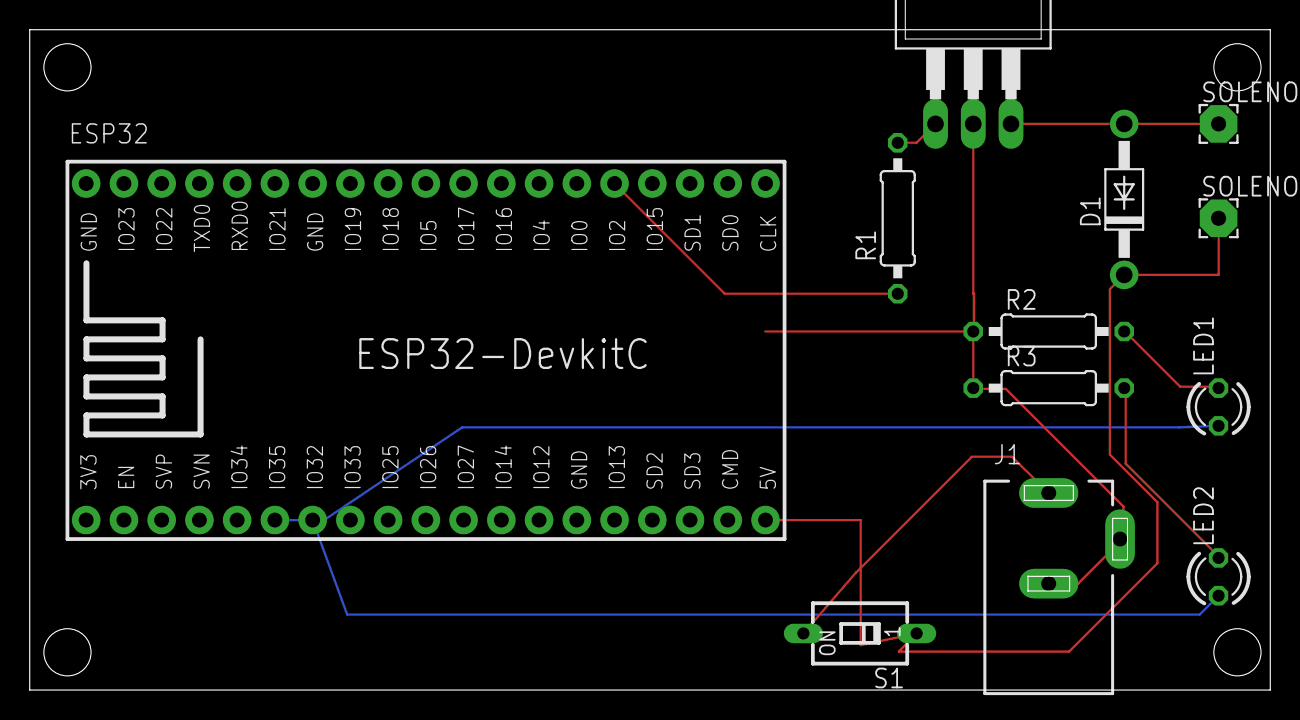
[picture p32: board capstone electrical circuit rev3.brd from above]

Board: 2 copper layers, 83.5 x 44.4 mm, 12 parts (0 on the bottom side), 10 nets.

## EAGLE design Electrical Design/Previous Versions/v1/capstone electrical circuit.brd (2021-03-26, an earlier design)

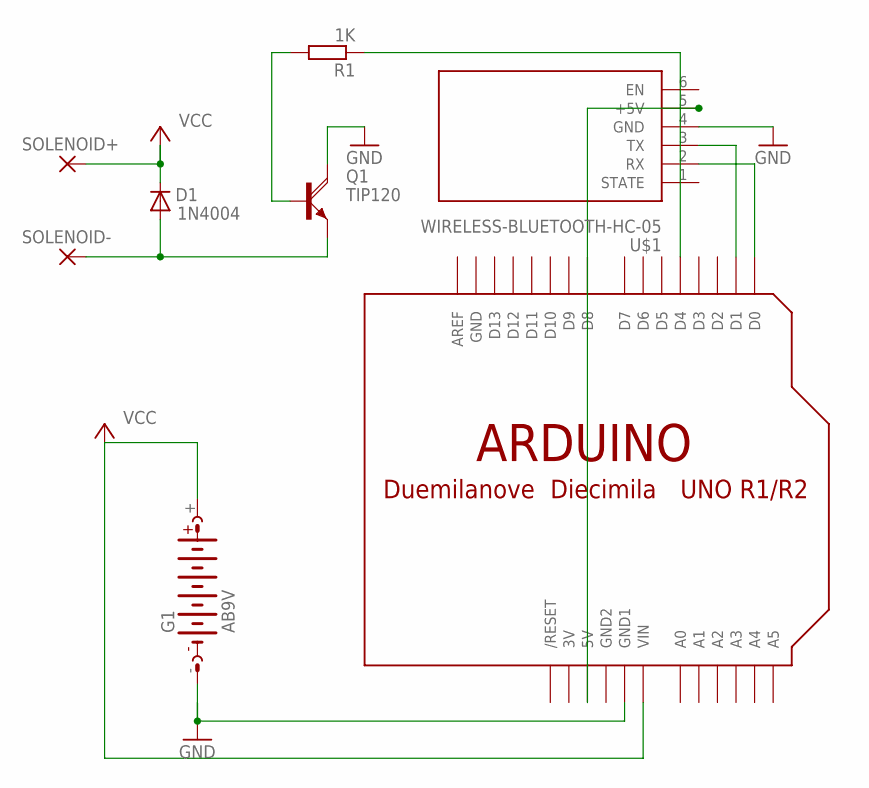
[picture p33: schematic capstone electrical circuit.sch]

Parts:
D1: 1N4004; DO41-10
G1: AB9V
Q1: TIP120; TO220AH
R1: 1K; 0207/10
SOLENOID+: WIREPAD2,54/1,0; 2,54/1,0
SOLENOID-: WIREPAD2,54/1,0; 2,54/1,0
U$1: WIRELESS-BLUETOOTH-HC-05
U$2: ARDUINOUNO; ARDUINO

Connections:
3V: U$2.3V
GND: G1.-, Q1.C, U$1.4 (GND), U$2.GND, U$2.GND1
GND2: U$2.GND2
unnamed: U$1.2 (RX), U$2.D0
unnamed: U$1.3 (TX), U$2.D1
unnamed: D1.A, Q1.E, SOLENOID-.1
unnamed: U$1.5 (+5V), U$2.5V
unnamed: Q1.B, R1.2
unnamed: R1.1, U$2.D4
VCC: D1.C, G1.+, SOLENOID+.1, U$2.VIN

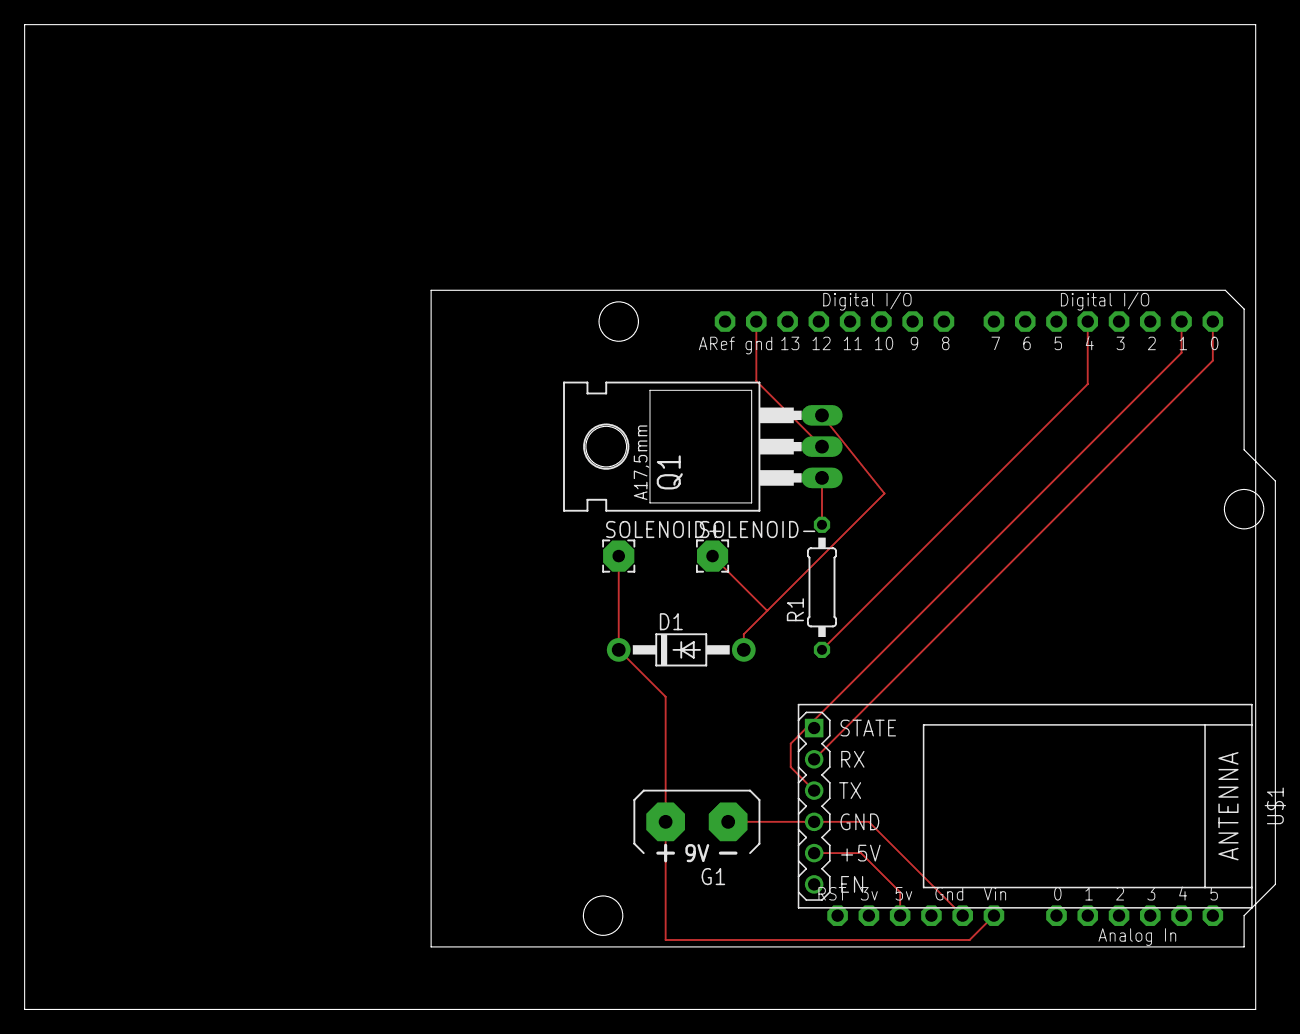
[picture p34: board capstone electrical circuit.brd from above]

Board: 2 copper layers, 101.6 x 80.0 mm, 8 parts (0 on the bottom side), 8 nets.

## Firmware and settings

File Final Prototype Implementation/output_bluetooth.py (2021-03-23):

from pythonosc import dispatcher, osc_server
import numpy as np
import tkinter as tk
import asyncio
import threading
import random
import os
import sys
import pandas as pd
import torch.utils.data
import torch.nn as nn
import torch.nn.functional as F
import matlab.engine
import serial
import time
from firebase import firebase
from scipy.signal import butter, filtfilt


def butter_bandpass(channel, low_cutoff, high_cutoff, fs, order):
    nyq = fs/2
    # Get the filter coefficients
    b, a = butter(order, [low_cutoff/nyq, high_cutoff/nyq], btype='band', analog=False)
    y = filtfilt(b, a, channel)
    return y

def bandpassFilterChannels(data, low_cutoff, high_cutoff, fs, order):
    for col in range(data.shape[1]):
        #Filter each column with 5th order butterworth bandpass
        data[:, col] = butter_bandpass(data[:, col], 0.5, 40, 256, 5)
    return data


def process(data):
    fs = 256
    data = bandpassFilterChannels(data, 0.5, 40, fs, 5)
    data = data.transpose()
    data = torch.from_numpy(data)
    data = data.unsqueeze(0)
    data = data.float()
    return data

class ANN_TS_3L(nn.Module):
    def __init__(self):
        super(ANN_TS_3L, self).__init__()
        self.name = "ANN_TS_3L"
        self.layer1 = nn.Linear((256*5)*4, 500)
        self.layer2 = nn.Linear(500, 200)
        self.layer3 = nn.Linear(200, 50)
        self.layer4 = nn.Linear(50, 2)
    def forward(self, img):
        flattened = img.reshape(-1, (256*5)*4)
        activation1 = F.relu(self.layer1(flattened))
        activation2 = F.relu(self.layer2(activation1))
        activation3 = F.relu(self.layer3(activation2))
        output = self.layer4(activation3)
        return output

def loadModels():
    torch.manual_seed(1)
    ANN = ANN_TS_3L()
    if use_cuda and torch.cuda.is_available():
        ANN = ANN.cuda()
        print("CUDA Available")

    model_path = path + "\\model_ANN_TS_3L_bs50_lr0-001_epoch72_iteration509_val-acc65-3333.pth"
    model = ANN

    if use_cuda and torch.cuda.is_available():
        model.load_state_dict(torch.load(model_path))
    else:
        model.load_state_dict(torch.load(model_path, torch.device('cpu')))

    return ANN

def checkOutput(recorded_signals,model):
    recorded_signals = np.array(recorded_signals, dtype='float64')
    data = process(recorded_signals)
    if use_cuda and torch.cuda.is_available():
        data = data.cuda()
    out = model(data)
    out = out.max(1, keepdim=True)[1]
    return out


def createWindow(title, backgroundColor, fullScreen=False):
# Returns a tk.tk() object with given title and background colour
    window = tk.Tk()
    window.title(title)
    if fullScreen:
        window.state('zoomed')
    window.configure(bg=backgroundColor)
    return window

def stopProgram(window):
    window.destroy()
    sys.exit(0)

def _asyncio_thread(async_loop, ip, port, info):
    async_loop.run_until_complete(recordEEG(ip, port, info, async_loop))

def do_tasks(async_loop, ip, port, info):
    """ Event-Handler starting the asyncio part. """
    threading.Thread(target=_asyncio_thread,
                     args=(async_loop, ip, port, info)).start()

def initializeRecording(window, info):
    ip = "127.0.0.1"
    port = 7000
    async_loop = asyncio.get_event_loop()
    window.after(int(info[3] * 1000),
                 lambda:do_tasks(async_loop, ip, port, info))

def eeg_handler(unused_addr, args, ch1, ch2, ch3, ch4, ch5):
    recorded_signal.append([ch1, ch2, ch3, ch4])

def horseshoe(unused_addr, args, ch1, ch2, ch3, ch4):
    connection.append((ch1, ch2, ch3, ch4))

async def loop(delay):
    """Open server for delay time"""
    await asyncio.sleep(delay)

async def init_main(ip, port, dispatcher, t, async_loop):
    server = osc_server.AsyncIOOSCUDPServer((ip, port), dispatcher, async_loop)
    transport, protocol = await server.create_serve_endpoint()  # Create datagram endpoint and start serving
    await loop(t)  # Enter main loop of program
    transport.close()  # Clean up serve endpoint


async def recordEEG(ip, port, info, async_loop):
    from pythonosc import dispatcher
    dispatcher = dispatcher.Dispatcher()
    dispatcher.map("/muse/eeg", eeg_handler, "EEG")
    dispatcher.map("/muse/elements/horseshoe", horseshoe, "Horseshoe")
    recorded_signal.clear()
    connection.clear()
    desired, Emoji, description, EEGDelay, EEGTime = info
    await (init_main(ip, port, dispatcher, EEGTime, async_loop))
    connection_unique.clear()
    unique = list(set(connection))
    for i in unique:
        connection_unique.append(i)


def showPromptWindow():
    info = ["Prompt", False, "Think 'Open' or 'Close'", 1, 8]
    windowTitle, emoji, description, EEGDelay, EEGTime = info
    backg = 'black'
    textColor = 'white'
    emojiColor = 'DeepSkyBlue'
    window = createWindow(windowTitle, backg)

    # Make labels

    descriptionLabel = tk.Label(master=window, text=description, foreground=textColor, bg=backg, font='Calibri 72')

    # Place labels on window
    descriptionLabel.pack(expand=True)

    # Record EEG
    initializeRecording(window, info)

    totalTime = EEGTime + EEGDelay + 1
    window.after(int(1000 * totalTime), lambda: window.destroy())  # destroy window after totalTime seconds
    window.protocol("WM_DELETE_WINDOW", lambda: stopProgram(window))  # kill all execution if user exits
    window.mainloop()

def showConnectionWindow():
    backg = 'black'
    textColor = 'white'
    window = createWindow("Bad Connection", backg)

    descriptionLabel = tk.Label(master=window, text="Poor Connection. Try Again.",
                                foreground=textColor, bg=backg, font='Calibri 72')
    descriptionLabel.pack(expand=True)

    totalTime = 3
    window.after(int(1000 * totalTime), lambda: window.destroy())  # destroy window after totalTime seconds
    window.protocol("WM_DELETE_WINDOW", lambda: stopProgram(window))  # kill all execution if user exits
    window.mainloop()

def showResultWindow(result):
    t = 1.5
    backg = 'black'
    textColor = 'white'
    if result == 0:
        Emoji = "🚱"
        description = "Close"
    else:
        Emoji = "🚰"
        description = "Open"

    color = 'DeepSkyBlue'
    window = createWindow("Result", backg)
    resultLabel = tk.Label(master=window, text=description, foreground=textColor, bg = backg, font='Calibri 72 bold')
    emojiLabel = tk.Label(master=window, text=Emoji, foreground=color, bg = backg, font='Calibri 150')
    resultLabel.pack(expand=True)
    emojiLabel.pack(expand=True)
    window.after(int(1000 * t), lambda: window.destroy())  # destroy window after restTime seconds
    window.protocol("WM_DELETE_WINDOW", lambda: stopProgram(window))  # kill all execution if user exits
    window.mainloop()
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

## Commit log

2021-02-27 Added Nov 2020 Filtered Data
    [AZ_T10 Open (valve) - FFT.csv, AZ_T10 Open (valve) - Filtered.csv, AZ_T10 Open (valve)_0 - FFT.csv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]
2021-02-27 Added Feb 2021 Filtered 5s
    [AZ_T10 Close (valve) - FFT.csv, AZ_T10 Close (valve) - Filtered.csv, AZ_T11 Open (valve) - FFT.csv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]
2021-02-27 Added Feb 2021 Filtered 2 x 3.5s
    [AZ_T10 Close (valve)_0 - FFT.csv, AZ_T10 Close (valve)_0 - Filtered.csv, AZ_T10 Close (valve)_1 - FFT.csv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]
2021-03-01 Changed folder names for consistency
    [AZ_T10 Open (valve)_0 - FFT.csv, AZ_T10 Open (valve)_0 - Filtered.csv, AZ_T10 Open (valve)_1 - FFT.csv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]
2021-03-16 Added downloaded model weights after training
    [model_ANN_TS_2L_bs50_lr0-01_epoch149_iteration1050_val-acc48-0_train_acc.csv, model_ANN_TS_2L_bs50_lr0-01_epoch149_iteration1050_val-acc48-0_train_loss.csv, mo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]
2021-03-18 Added summary results spreadsheet
    Added spreadsheet to show dataset composition and accuracy results segmented by person and class
    [Final Model Test Results Summary.xlsx]
2021-03-22 Added raw EEG data collection scripts
    [SSVEP Trials List.xlsx]
2021-03-23 Edited Result Table Fonts
    [Final Model Test Results Summary.xlsx]
2021-03-23 Added code for using model in real-time with valve
2021-03-25 Printed out dataset split
2021-03-26 Added CAD Assemblies
    [55675-1.SLDPRT, Bathroom_faucet.SLDASM, CAGE.SLDPRT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]

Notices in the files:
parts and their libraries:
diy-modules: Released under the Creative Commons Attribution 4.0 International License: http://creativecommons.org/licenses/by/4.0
